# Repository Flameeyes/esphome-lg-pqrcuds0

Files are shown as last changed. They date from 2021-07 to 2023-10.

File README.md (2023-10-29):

<!--
SPDX-FileCopyrightText: 2021 Diego Elio Pettenò

SPDX-License-Identifier: 0BSD
-->

# LG PQRCUDS0 compatible ESPHome Component

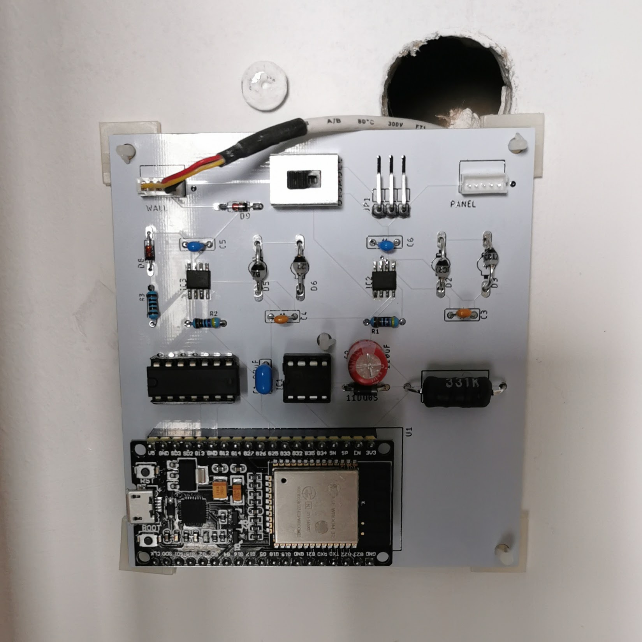
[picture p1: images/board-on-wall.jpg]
The custom board on the wall


This repository contains the source code and the EAGLE design files for using
[ESPHome](https://esphome.io/) to control a LG air conditioning unit that uses
the PQRCUDS0 control panel.

The source code and an example configuration package are in the `esphome/`
directory, while the `eagle/` directory has the PCB design files.

Note that this project is neither endorsed, nor sponsored, by either of LG
or the ESPHome project.

You can find details of the implementation and some of the choices made in the
design on my blog: https://flameeyes.blog/tag/lg-pqrcuds0/

See also:

* Python utilities to emulate the panel and engine at
    <https://github.com/Flameeyes/lg-PQRCUDS0-emu>
* [Saleae Logic](https://www.saleae.com/) high-level analyzer for the
  protocol, at <https://github.com/Flameeyes/saleae-extension-LG-PQRCUDS0>

## Features

The custom component needs [Home Assistant](https://www.home-assistant.io/),
to provide a reference temperature, as it does not provide its own temperature
sensor.

Once provided a reference temperature sensor, the component supports the
following features, tested on my flat's HVAC system (LG ARNU07GB1G2):

* Cool, heat, fan-only, dehumidifer, and heat-cool modes, with two-point set
  temperature.

* Fan speed selection (low/medium/high), including "off" speed for idling in
  heat-cool mode.

## Board Revision History

### Rev 1

Original production design. It provided support to host the panel to the side
for going back to the panel on request, with a cutoff switch.

The cutoff had problems with holding the HVAC unit and the panel in sync when
switching away from the ESP32, so it never really worked.

The other reason to keep te panel powered up would have been to maintain a
readout of the temperature from the panel's on-board temperature sensor, but
it does not appear to be very reliable or useful, being able to report only
between 18C and 30C.

### Rev 2

A size- and cost-reduced variant of the original board, with the same logic
design, but without the secondary bus (and related components), and replacing
the cutoff switch with a pushbutton that turns off the whole board.

The bus connector is now on the back of the board, to make it easier to access
from the wall itself.

## License

Both the custom component and the EAGLE design files are released under the
permissive 0BSD license. This means you can reuse them pretty much as you may
want to.

Do note that ESPHome libraries are licensed under GNU GPLv3, so combining them
with logic in the components is still subject to the full license.

## Boxes

The `boxes/` directory contains 3D printable files for a box compatible with
the rev2 board.

Since this is literally my first 3D design, take it with a grain of salt,
it particularly suffers from the following minor issues:

* The cover vents on the top are not shaped to keep into consideration the
  registration corners.
* The central screw is unnecessary as (at least with Nylon SLS print) it is
  perfectly possible to keep the box closed by friction-fitting it.
* There should be a little more clearance for the ESP32 module, by raising
  the top of the cover.
* There's no compatible cap to fit into the pushbutton. A different strategy
  should be pursued.
* The keyholes should be more tolerant, as screws are often not quite aligned
  as they should be.

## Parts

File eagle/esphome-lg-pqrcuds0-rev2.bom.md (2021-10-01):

<!--
SPDX-FileCopyrightText: 2021 Diego Elio Pettenò

SPDX-License-Identifier: 0BSD
-->

# Bill Of Material for esphome-lg-pqrcuds0-rev1

Note: approximate cost applied to based on Digikey on 2021-08-01.

Prices are read in GBP before VAT, and for a single item.

| Quantity | Code | Cost Per Unit | Total Cost |
| --- | --- | --- | --- |
| 1 | S5B-ZR(LF)(SN) | £0.21 | £0.21 |
| 2 | 1N4148 | £0.07 | £0.14 |
| 1 | TL2230EEF140 | £0.64 | £0.64 |
| 1 | TLIN1027DRQ1 | £0.76 | £0.76 |
| 2 | BZT03C27-TAP | £0.47 | £0.94 |
| 1 | FG28X5R1H105KRT06  | £0.27 | £0.27 |
| 1 | K221K10X7RF5UH5 | £0.14 | £0.14 |
| 1 | 4.7kΩ resistor | £0.0034 | £0.0034 |
| 1 | 1kΩ resistor | £0.00345 | £0.00345 |
| 1 | LM2574-3.3YN | £1.22 | £1.22 |
| 1 | SB150-E3 | £0.29 | £0.29 |
| 1 | A759EK226M1JAAE054 | £0.39 | £0.39 |
| 1 | 860020474012 | £0.16 | £0.16 |
| 1 | AIAP-02-331K | £0.49 | £0.49 |
| 2 | PPTC191LFBN-RC | £0.84 | £1.68 |
| 1 | ESP32-DEVKITC-32D  | £7.16 | £7.16 |

Total: £14.50

## Cost Saving Ideas

The BZT03C27-TAP pair could be replaced with an integrated TVS diode like the
MMBZ27VALT3G (though surface mount) for £0.16.

The ESP32-DEVKIT-32D could be replaced with a WROOM module and the correct
passives, which would probably bring down the main cost by £5 or so between
the module itself, and the sockets.

The LM2574-3.3YN could be replaced with a linear regulator, given that the
panel no longer needs to be supplied in parallel.

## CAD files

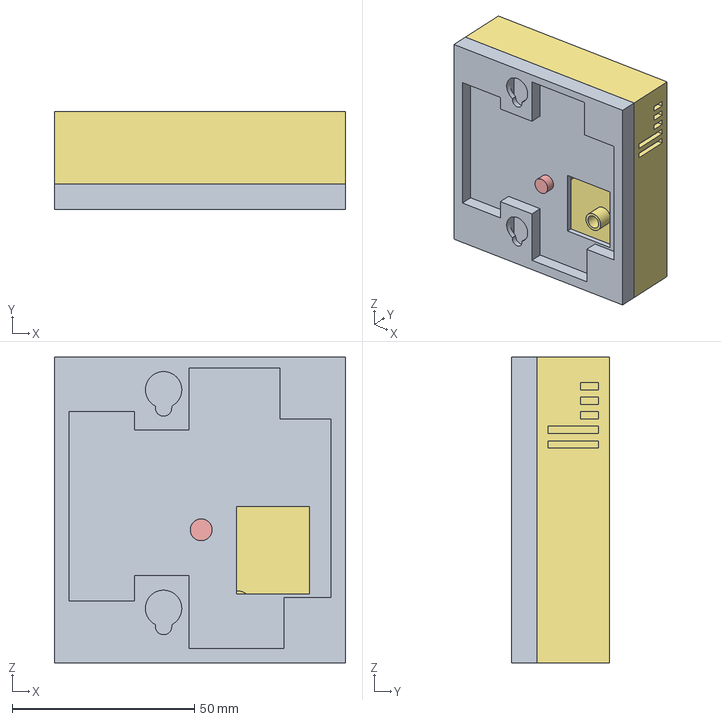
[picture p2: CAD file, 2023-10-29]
boxes/rev2-complete.3mf
80.0 x 27.0 x 84.0 mm

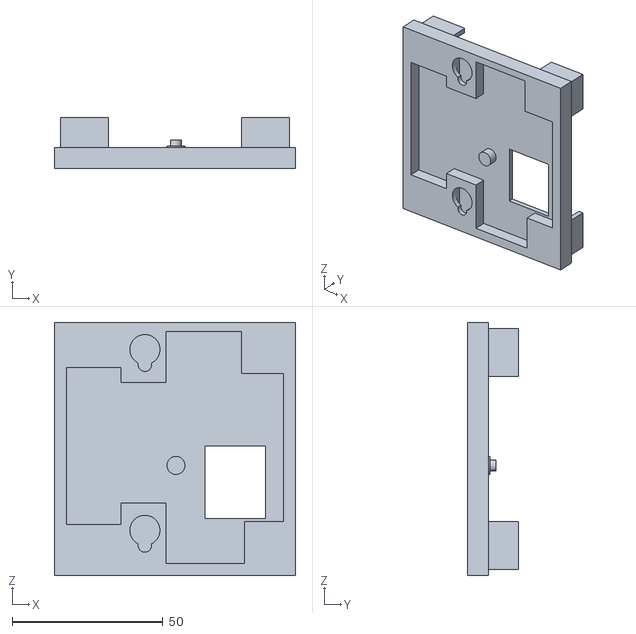
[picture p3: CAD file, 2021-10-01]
boxes/rev2-backplate.stl
80.0 x 17.0 x 84.0

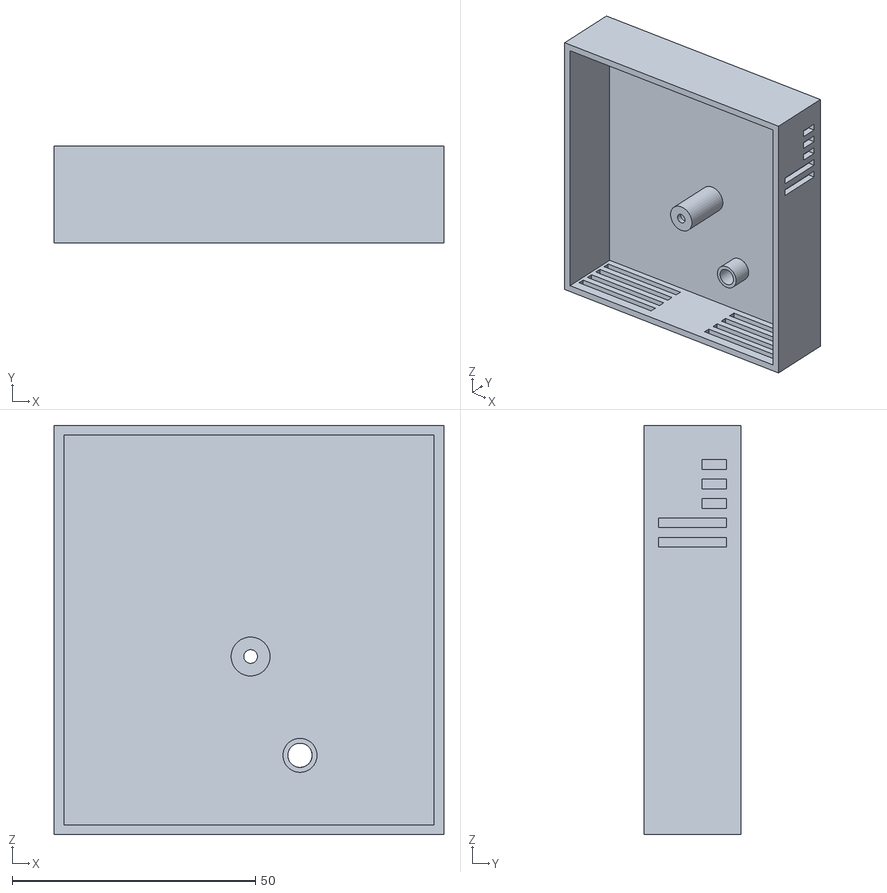
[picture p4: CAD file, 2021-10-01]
boxes/rev2-cover.stl
80.0 x 20.0 x 84.0

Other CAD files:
boxes/rev2-complete.f3z

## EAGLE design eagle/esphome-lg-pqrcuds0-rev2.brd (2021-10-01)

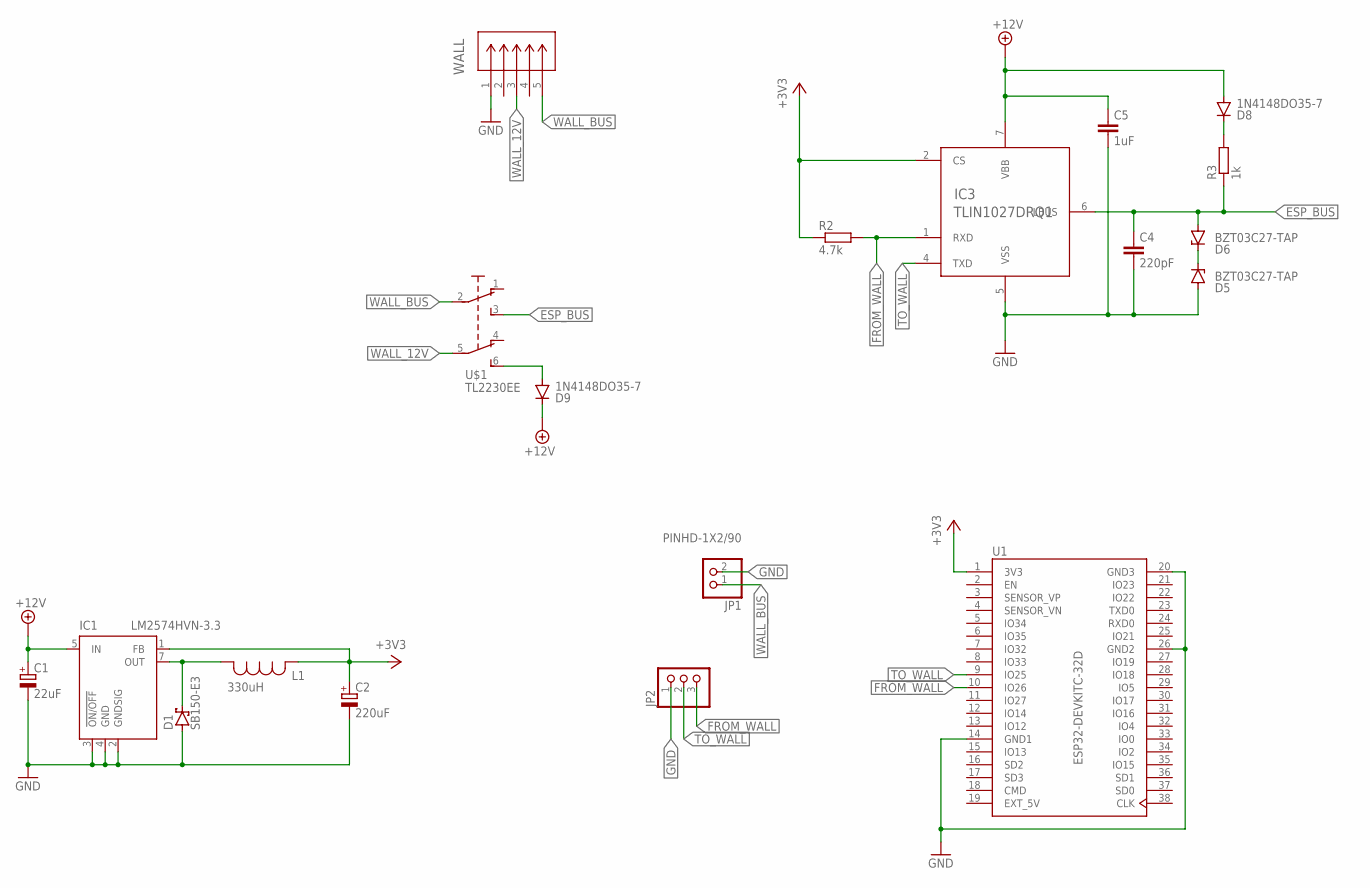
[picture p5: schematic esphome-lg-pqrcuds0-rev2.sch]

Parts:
C1: 22uF; E2,5-6
C2: 220uF; E2,5-6E
C4: 220pF; C050-025X075
C5: 1uF; C050-025X075
D1: SB150-E3; DO35-7
D5, D6: BZT03C27-TAP; SOD57Z10
D8, D9: 1N4148DO35-7; DO35-7
IC1: LM2574HVN-3.3; DIL08
IC3: TLIN1027DRQ1; SOIC8
JP1: PINHD-1X2/90; 1X02/90
JP2: PINHD-1X3/90; 1X03/90
L1: 330uH; AIAP-02_ABR
R2: 4.7k; 0204/7
R3: 1k; 0204/7
U1: ESP32-DEVKITC-32D; MODULE_ESP32-DEVKITC-32D
U$1: TL2230EE; TL2230
WALL: S5B-ZR(LF)(SN); CONN_S5B-ZR_JST

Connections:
+3V3: C2.+, IC1.1 (FB), IC3.2 (CS), L1.2, R2.1, U1.1 (3V3)
+12V: C1.+, C5.1, D8.A, D9.C, IC1.5 (IN), IC3.7 (VBB)
ESP_BUS: C4.1, D6.A, IC3.6 (LBUS), R3.1, U$1.3 (S)
EXT_5V: U1.19 (EXT_5V)
FROM_WALL: IC3.1 (RXD), JP2.3, R2.2, U1.10 (IO26)
GND: C1.-, C2.-, C4.2, C5.2, D1.A, D5.A, IC1.2 (GNDSIG), IC1.3 (!ON/OFF), IC1.4 (GND), IC3.5 (VSS), JP1.2, JP2.1, U1.14 (GND1), U1.20 (GND3), U1.26 (GND2), WALL.1
unnamed: D9.A, U$1.6 (S1)
unnamed: D1.C, IC1.7 (OUT), L1.1
unnamed: D8.C, R3.2
unnamed: D5.C, D6.C
TO_WALL: IC3.4 (TXD), JP2.2, U1.9 (IO25)
WALL_12V: U$1.5 (P1), WALL.3
WALL_BUS: JP1.1, U$1.2, WALL.5

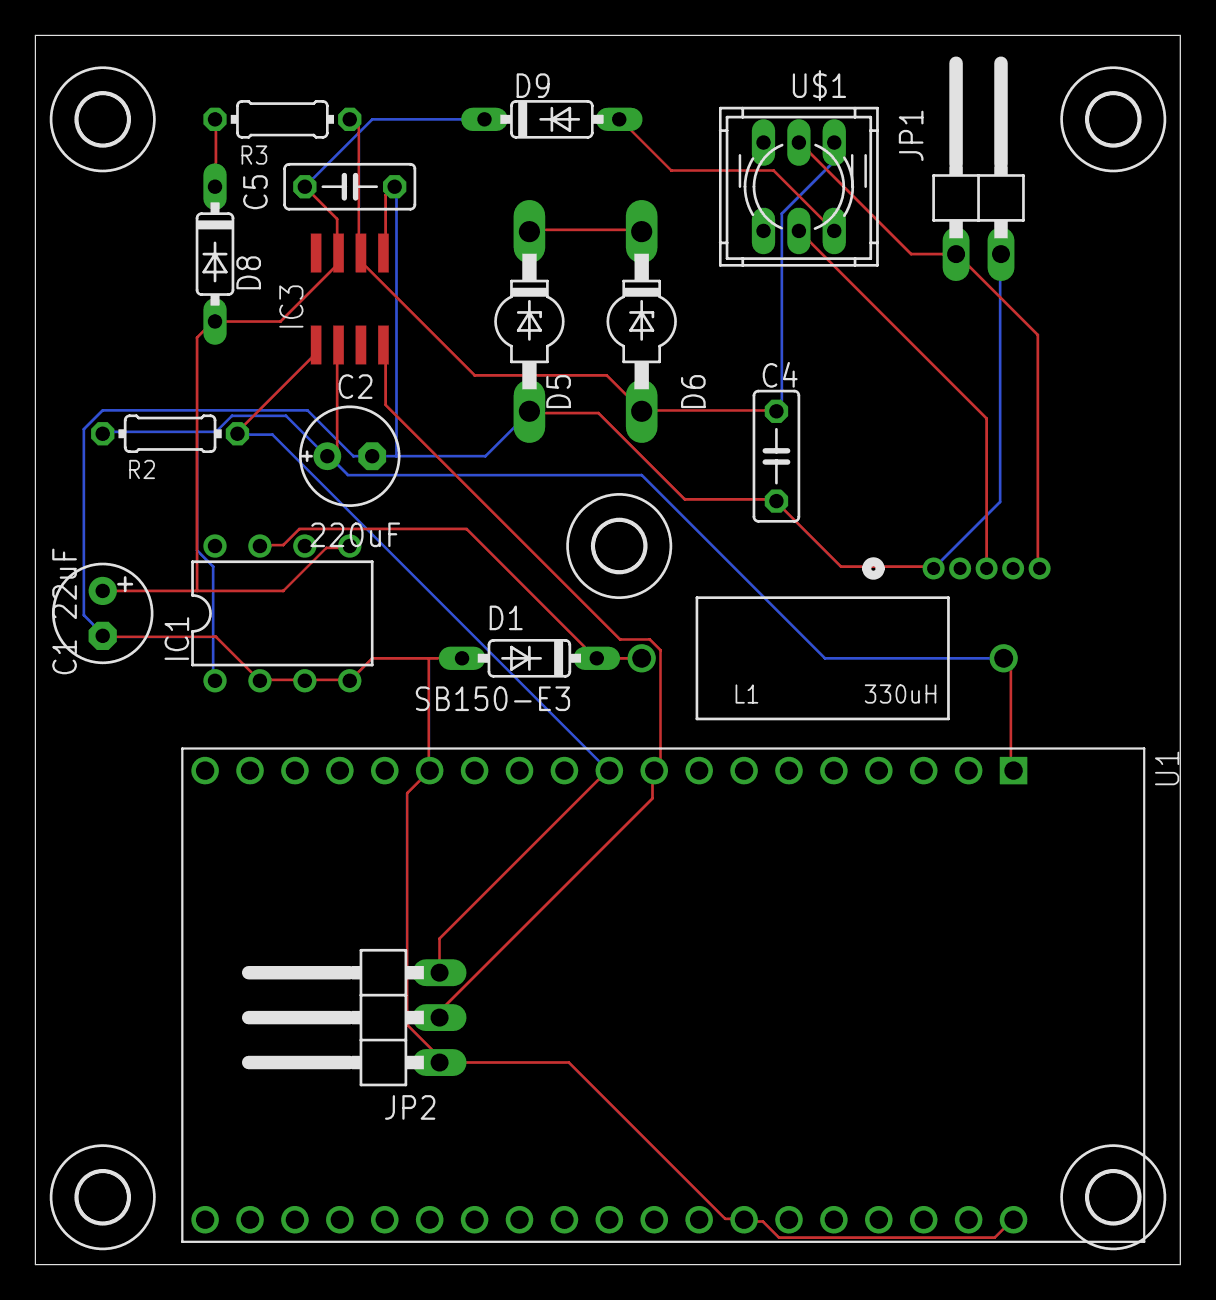
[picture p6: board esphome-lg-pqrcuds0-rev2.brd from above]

Board: 2 copper layers, 64.8 x 69.5 mm, 24 parts (1 on the bottom side), 12 nets.

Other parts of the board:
U$2, U$3, U$4, U$5, U$6: 2,8

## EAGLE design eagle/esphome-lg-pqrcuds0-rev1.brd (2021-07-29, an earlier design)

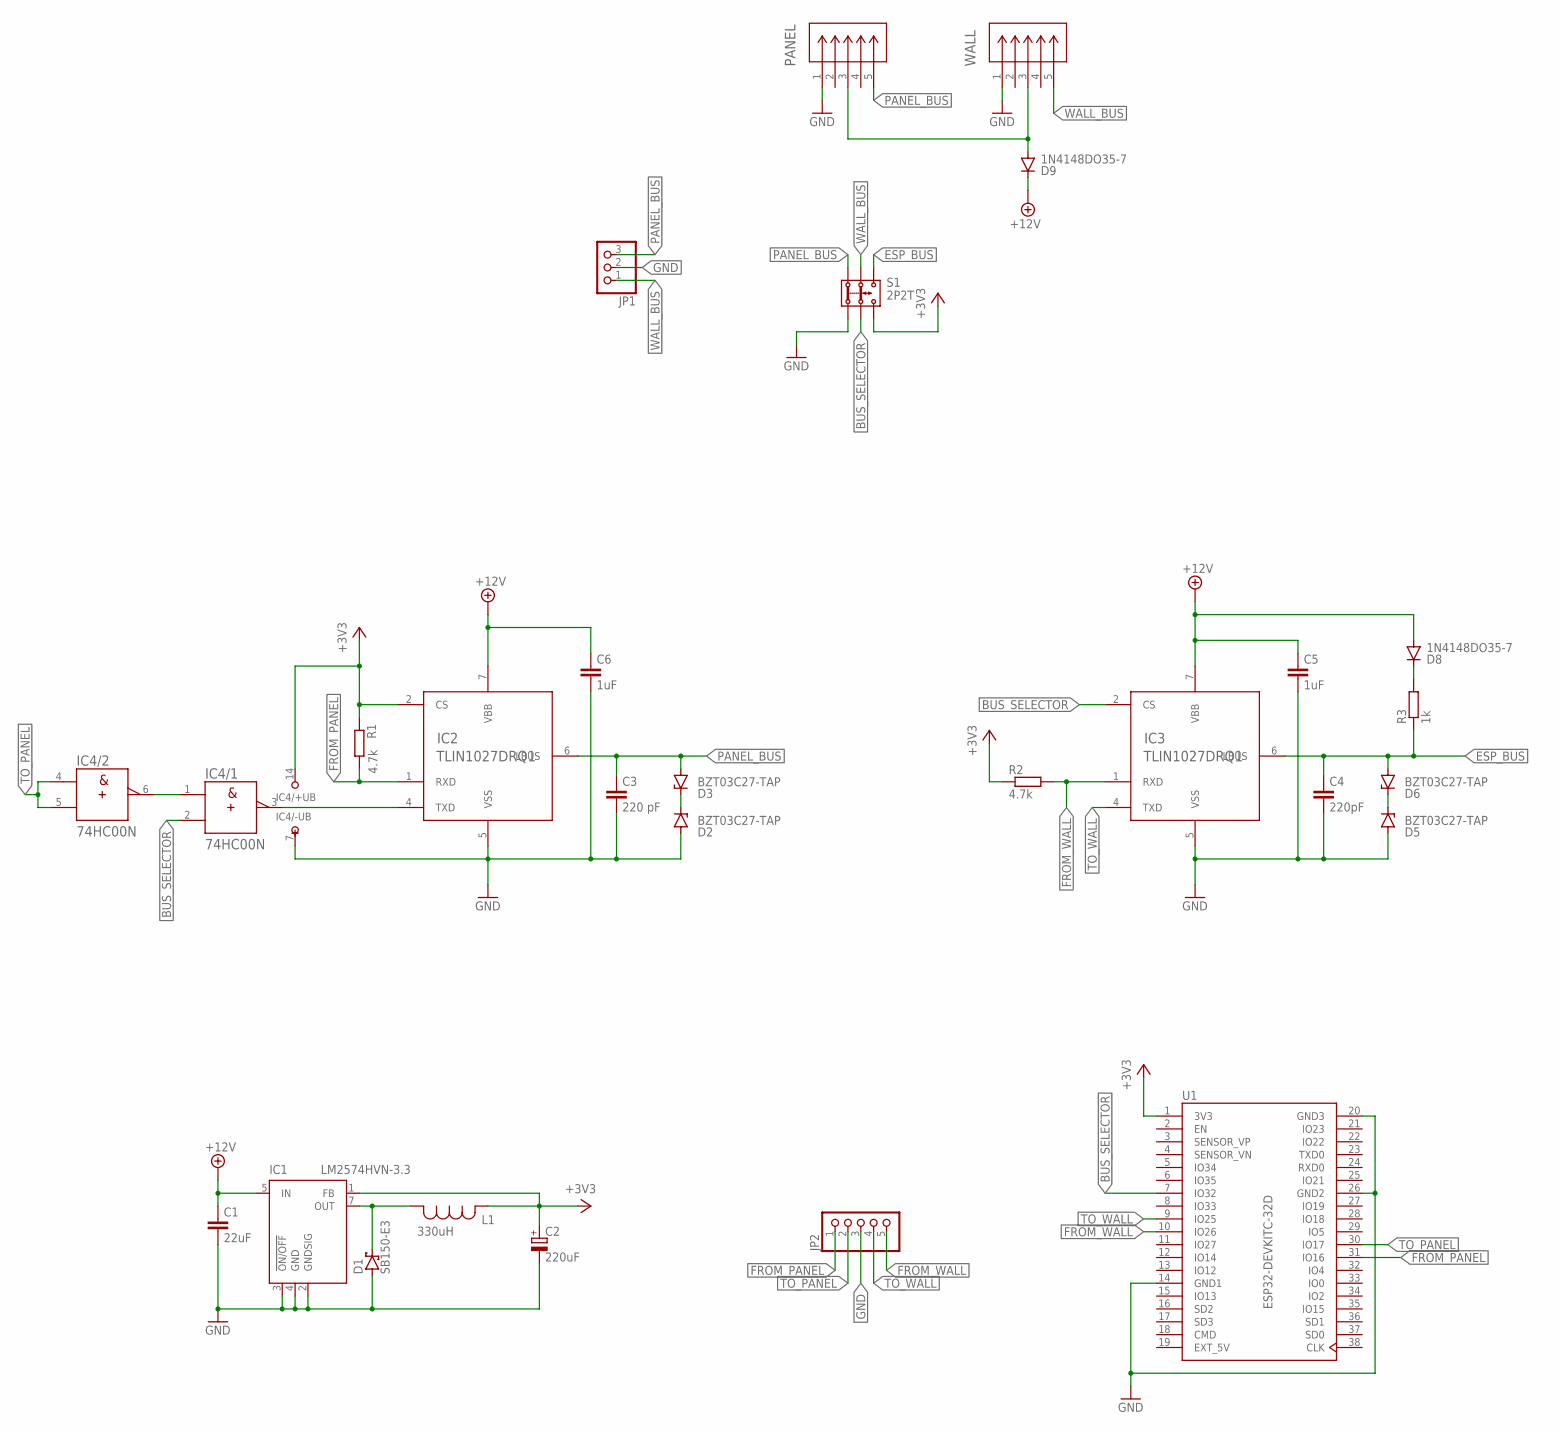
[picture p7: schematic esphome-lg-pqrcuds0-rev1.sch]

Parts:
C1: 22uF; C050-025X075
C2: 220uF; E2,5-6E
C3: 220 pF; C050-025X075
C4: 220pF; C050-025X075
C5, C6: 1uF; C050-025X075
D1: SB150-E3; DO35-7
D2, D3, D5, D6: BZT03C27-TAP; SOD57Z10
D8, D9: 1N4148DO35-7; DO35-7
IC1: LM2574HVN-3.3; DIL08
IC2, IC3: TLIN1027DRQ1; SOIC8
IC4: 74HC00N; DIL14
JP1: PINHD-1X3/90; 1X03/90
JP2: PINHD-1X5/90; 1X05/90
L1: 330uH; AIAP-02_ABR
PANEL: S5B-ZR(LF)(SN); CONN_S5B-ZR_JST
R1, R2: 4.7k; 0204/7
R3: 1k; 0204/7
S1: 2P2T
U1: ESP32-DEVKITC-32D; MODULE_ESP32-DEVKITC-32D
WALL: S5B-ZR(LF)(SN); CONN_S5B-ZR_JST

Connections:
+3V3: C2.+, IC1.1 (FB), IC2.2 (CS), IC4.14 (+UB), L1.2, R1.1, R2.1, S1.3.2, U1.1 (3V3)
+12V: C1.1, C5.1, C6.1, D8.A, D9.C, IC1.5 (IN), IC2.7 (VBB), IC3.7 (VBB)
BUS_SELECTOR: IC3.2 (CS), IC4.2 (B), S1.2.2, U1.7 (IO32)
ESP_BUS: C4.1, D6.A, IC3.6 (LBUS), R3.1, S1.3.1
EXT_5V: U1.19 (EXT_5V)
FROM_PANEL: IC2.1 (RXD), JP2.1, R1.2, U1.31 (IO16)
FROM_WALL: IC3.1 (RXD), JP2.5, R2.2, U1.10 (IO26)
GND: C1.2, C2.-, C3.2, C4.2, C5.2, C6.2, D1.A, D2.A, D5.A, IC1.2 (GNDSIG), IC1.3 (!ON/OFF), IC1.4 (GND), IC2.5 (VSS), IC3.5 (VSS), IC4.7 (-UB), JP1.2, JP2.3, PANEL.1, S1.1.2, U1.14 (GND1), U1.20 (GND3), U1.26 (GND2), WALL.1
unnamed: D1.C, IC1.7 (OUT), L1.1
unnamed: D8.C, R3.2
unnamed: IC2.4 (TXD), IC4.3 (Y)
unnamed: IC4.1 (A), IC4.6 (Y)
unnamed: D9.A, PANEL.3, WALL.3
unnamed: D2.C, D3.C
unnamed: D5.C, D6.C
PANEL_BUS: C3.1, D3.A, IC2.6 (LBUS), JP1.3, PANEL.5, S1.1.1
TO_PANEL: IC4.4 (A), IC4.5 (B), JP2.2, U1.30 (IO17)
TO_WALL: IC3.4 (TXD), JP2.4, U1.9 (IO25)
WALL_BUS: JP1.1, S1.2.1, WALL.5

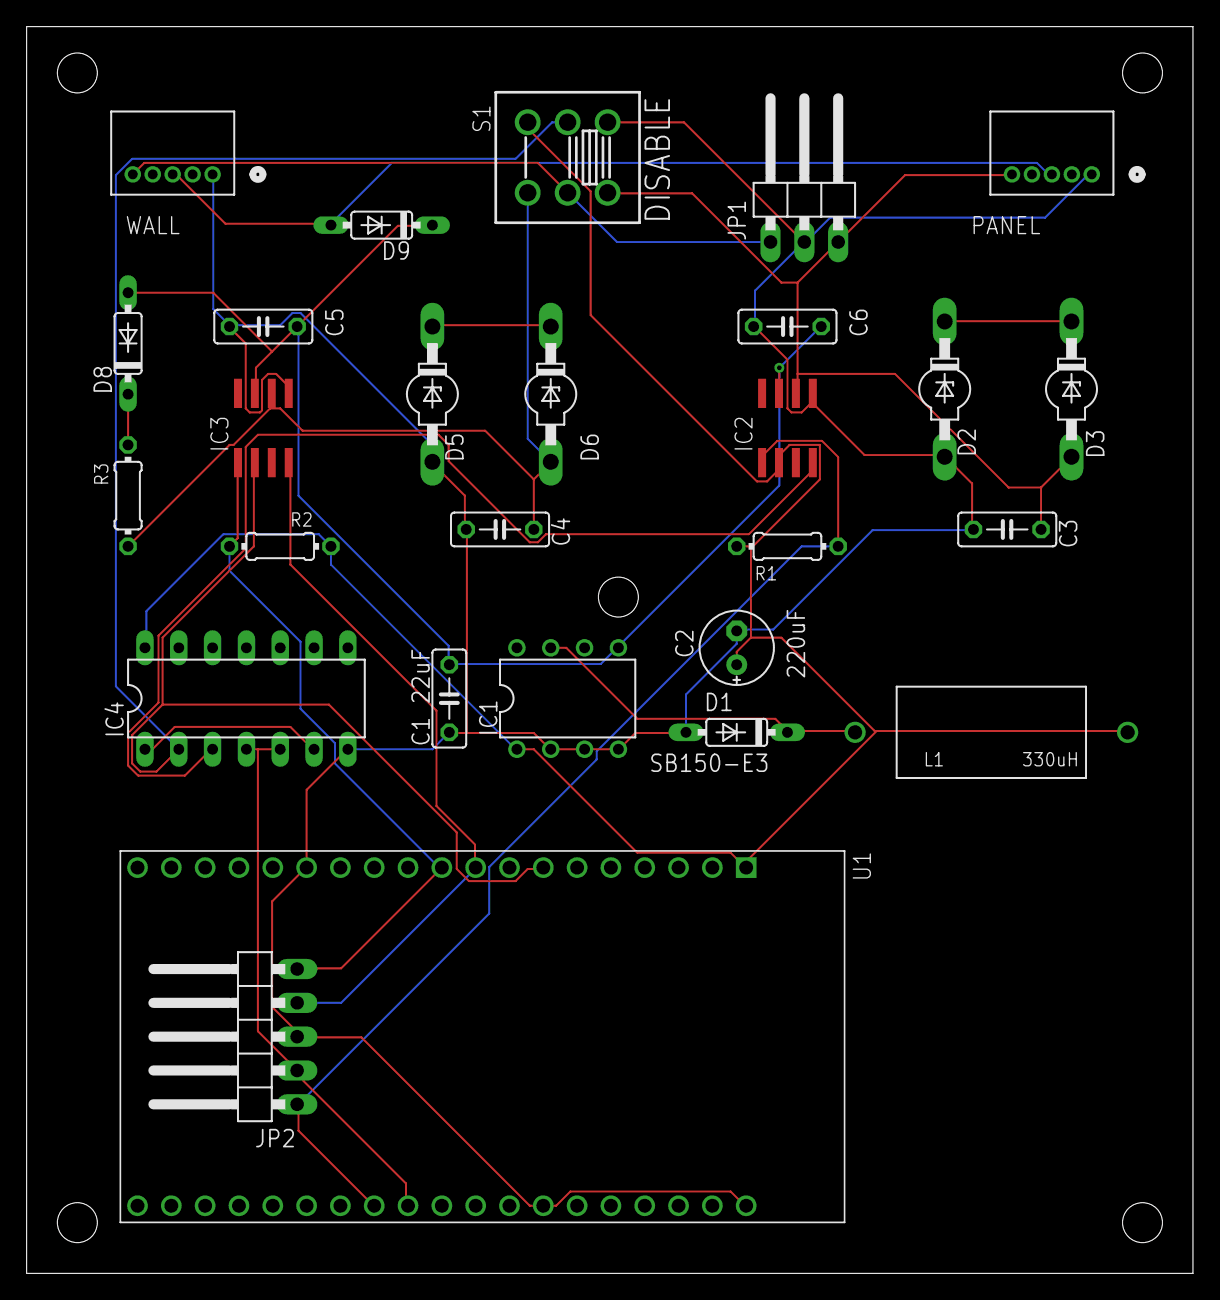
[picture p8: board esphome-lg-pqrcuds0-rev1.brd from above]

Board: 2 copper layers, 87.6 x 93.6 mm, 27 parts (0 on the bottom side), 18 nets.

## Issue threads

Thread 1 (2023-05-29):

Using with ESPHOME / home assistant

bleughb, 2023-05-29:
Hi,
I'm quite new to ESPhome / home assistant ,
i've spent a good day or so trying to figure out how your code works and how to get it to be installed!, i'm failing

Figured out that to include the .h file you need to reference the local directory with a folder in the esphome dir - i just copied the examples i found.......

external_components:
  - source:
      type: local
      path: my_components

My latest issue is the  line -
entity_id: ${reference_temperature}

the compiler oming up with the error
"Entity ID must have exactly one dot in it."

then when you remove the braces, it compiles with another error
and when you add a . it comes up with another

' ' '
/config/esphome/esphome-web-df7188.yaml:60:30: error: expected type-specifier before 'LgHvac'
       auto lg_pqrcuds0 = new LgHvac(id(wall_uart), id(reference_temperature));
                              ^~~~~~
/config/esphome/esphome-web-df7188.yaml:62:26: error: could not convert '{lg_pqrcuds0}' from '<brace-enclosed initializer list>' to 'std::vector<esphome::climate::Climate*>'
       return {lg_pqrcuds0};
                          ^
*** [/data/esphome-web-df7188/.pioenvs/esphome-web-df7188/src/main.cpp.o] Error 1
' ' '

Flameeyes, 2023-05-29:
I think I might need to update the example a little bit for the more recent versions of ESPHome configs.

Though unless something changed on the last couple of months, the include just needs to be in the same directory as the config itself.

As for the reference temperature, you need to provide it with a sensor ID from your Home Assistant installation that represent the temperature of the room you want to control. I use an average between a Dyson fan temperature and a thermometer on the back of my chair for my home office climate.

bleughb, 2023-05-29:
Thankyou for the quick reply!
I tried putting that .h file 'everywhere' just to see if it would pickup at all...zilch till I added the local reference

have renamed a sensor here to reference_temperature, but still getting
an error when compiling it

sensor.homeassistant: [source /config/esphome/esphome-web-df7188.yaml:52]
  platform: homeassistant
  id: reference_temperature
  internal: True

  Entity ID must have exactly one dot in it.
  entity_id: ${reference_temperature}

Flameeyes, 2023-05-29:
Your file should look something like:

```
# SPDX-FileCopyrightText: 2021 Diego Elio Pettenò
#
# SPDX-License-Identifier: 0BSD

esphome:
  name: study-climate
  friendly_name: Study Climate

  includes:
    - lg-pqrcuds0.h

esp32:
  board: esp-wrover-kit
  framework:
    type: esp-idf
    version: recommended

uart:
  - id: wall_uart
    tx_pin: GPIO25
    rx_pin: GPIO26
    baud_rate: 104

sensor:
  - id: reference_temperature
    platform: homeassistant
    internal: true
    entity_id: sensor.study_temperature  # This needs to exist in Home Assistant already!

climate:
  - platform: custom
    lambda: |-
      auto lg_pqrcuds0 = new LgHvac(id(wall_uart), id(reference_temperature));
      App.register_component(lg_pqrcuds0);
      return {lg_pqrcuds0};

    climates:
      - name: Climate
 ```

And then the `.h` file should be in `/config/esphome` of your Home Assistant installation just like the `yml` file.

Note that over there I have omitted the various basic config for API and Home Assistant integration as well as WiFi configuration.

bleughb, 2023-05-29:
getting closer!

it's compiling with a different error now

`/config/esphome/esphome-web-df7188.yaml: In lambda function:
/config/esphome/esphome-web-df7188.yaml:58:30: error: expected type-specifier before 'LgHvac'
       auto lg_pqrcuds0 = new LgHvac(id(wall_uart), id(reference_temperature));
                              ^~~~~~
/config/esphome/esphome-web-df7188.yaml:60:26: error: could not convert '{lg_pqrcuds0}' from '<brace-enclosed initializer list>' to 'std::vector<esphome::climate::Climate*>'
       return {lg_pqrcuds0};
                          ^
Compiling /data/esphome-web-df7188/.pioenvs/esphome-web-df7188/lib64d/WiFi/WiFiClient.cpp.o
Archiving /data/esphome-web-df7188/.pioenvs/esphome-web-df7188/lib133/libAsyncTCP-esphome.a
*** [/data/esphome-web-df7188/.pioenvs/esphome-web-df7188/src/main.cpp.o] Error 1
Compiling /data/esphome-web-df7188/.pioenvs/esphome-web-df7188/lib64d/WiFi/WiFiGeneric.cpp.o
========================= [FAILED] Took 24.79 seconds =========================`

bleughb, 2023-05-30:
A further update that may be important after watching your videos and trying to figure out ,
i'm using the Home assistant ESPHome add-on to install and configure your code -

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

bleughb, 2023-05-30:
Solved!  - you have to be very careful with indentations in yaml files

decided to install ESPhome standalone and played with VScode and the  ESPhome plugin

I was mistakenly doing the includes starting on the beginning of a new line rather than having it as the same indentation of the esphome lines

I'm now compiling!

Closed 2023-05-30.

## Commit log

2021-07-29 Initial commit
    This imports the boards I actually had printed with no changes,
    which is not great because the silkscreen is missing, but for now
    I'm just going to "code dump" this here.
    [esphome-lg-pqrcuds0-rev1.brd, esphome-lg-pqrcuds0-rev1.sch]
2021-07-31 Add a photo, some notes about the board design.
2021-08-01 Add a Bill-of-Materials.
2021-10-01 Introduce rev2 of the replacement board.
    The new revision of the board has fewer "dead" features, but is also half the size.
    It only includes a single bus, because the panel itself is not useful, and it has a power button instead of a toggle.
    [esphome-lg-pqrcuds0-rev2.brd, esphome-lg-pqrcuds0-rev2.sch]
2021-10-01 Add STL files for the box.
    [rev2-backplate.stl, rev2-cover.stl]
2022-09-11 esphome: remove compile warnings by throwing an errors.
    There is no chance for these switch statements to have the values that
    the compiler complains about, but having the default case this can be
    avoided entirely.
2022-12-11 Rework hystheresis to correctly handle both heat and cool.
    The logic is a bit complicated, but we want to make sure we don't short-cycle the HVAC.
2022-12-17 Compensate for possible de-syncs.
    This might happen more likely when updating ESPHome.
2023-05-29 esphome config: update example to modern standard.
    This switches the example over to use ESP-IDF
    as well as using friendly names.
    It also includes a little documentation on how
    to configure the substitutions.
2023-10-29 Add more "sourcy" versions of the box itself.
    Instead of just including the generated STL, this *should* include the whole Fusion 360 history.
    And the 3MF should be more appropriate to make edits to, if needed.
    [rev2-complete.3mf, rev2-complete.f3z]

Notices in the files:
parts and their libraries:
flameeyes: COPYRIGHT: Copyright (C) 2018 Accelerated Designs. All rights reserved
